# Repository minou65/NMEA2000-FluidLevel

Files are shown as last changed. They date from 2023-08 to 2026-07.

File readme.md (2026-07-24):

# NMEA 2000 Fluidmonitor

<table>
  <tr>
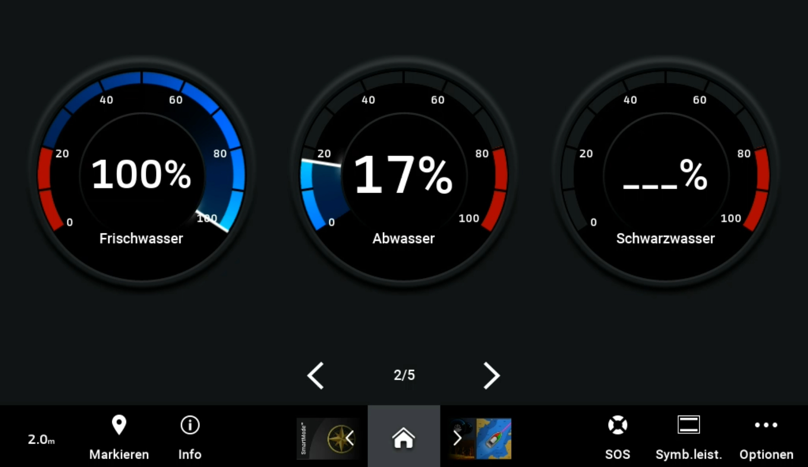
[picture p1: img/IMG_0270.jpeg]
NMEA 2000 Fluidmonitor
    <td></td>
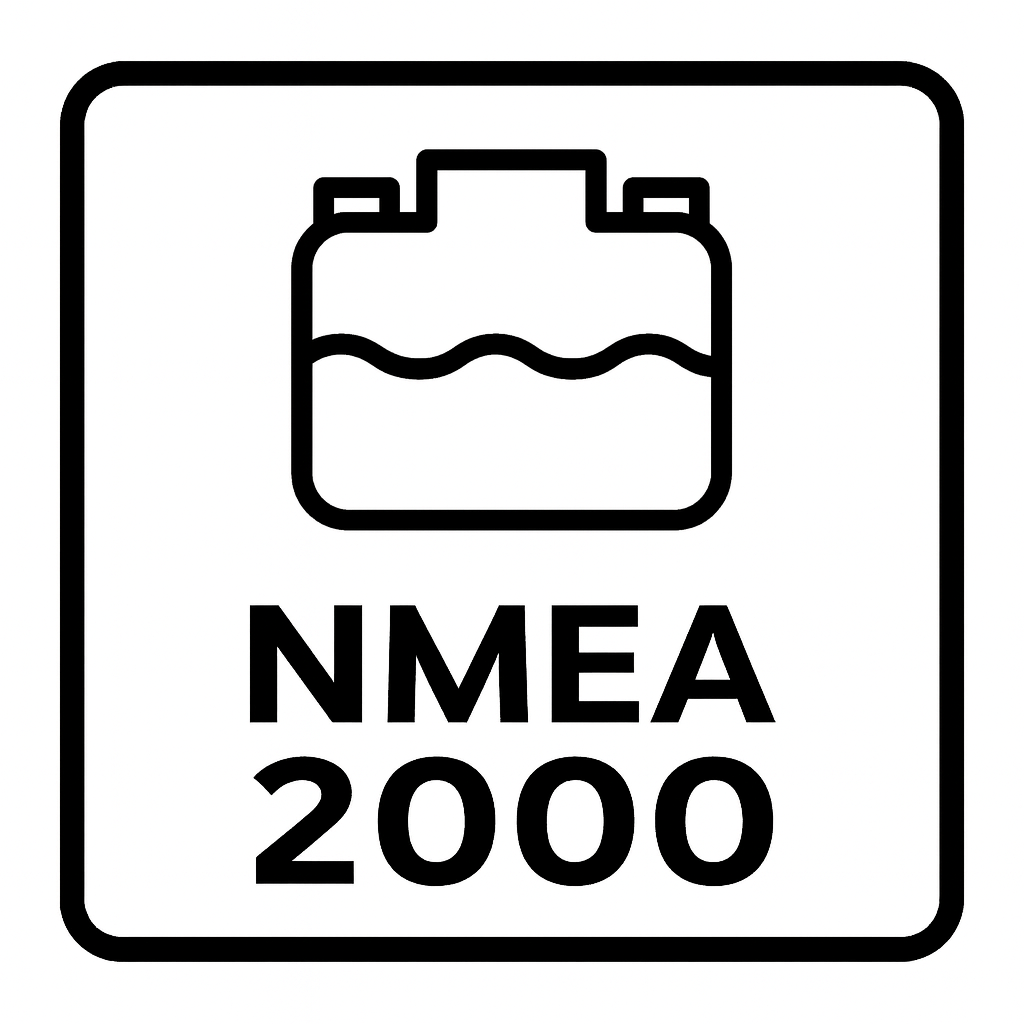
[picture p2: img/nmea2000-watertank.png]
NMEA 2000 Fluidmonitor icon
    <td align="right" valign="top" style="padding-left: 200px;"></td>
  </tr>
</table>

## Table of contents
- [NMEA 2000 Fluidmonitor](#nmea-2000-fluidmonitor)
  - [Table of contents](#table-of-contents)
  - [Important Hint](#important-hint)
  - [Description](#description)
  - [Related Projects](#related-projects)
  - [Hardware](#hardware)
  - [NMEA 2000](#nmea-2000)
  - [Libraries](#libraries)
  - [Configuration](#configuration)
    - [System Configuration](#system-configuration)
    - [NMEA 2000 Settings](#nmea-2000-settings)
    - [Tank](#tank)
    - [Sensor Calibration](#sensor-calibration)
  - [First Start](#first-start)
    - [Default IP address](#default-ip-address)
  - [Operation](#operation)
    - [Web UI (Home/Monitoring page)](#web-ui-homemonitoring-page)
      - [Sensor damping behavior](#sensor-damping-behavior)
    - [Firmware Update](#firmware-update)
    - [Blinking codes](#blinking-codes)
    - [Reset](#reset)

## Important Hint
Although the term NMEA2000 is used here, the software and device are **not certified NMEA2000 products** and have not passed any official approval process. There is a possibility that the software or hardware does not fully comply with the NMEA2000 specification in all details. If you connect this device to your NMEA2000 network, you do so at your own risk.

## Description

Note: This project also provides one branch each for the VL53L1X sensor variant and the VL53L0X sensor variant.

A resistive sensor-based system to determine the fill level in a tank. This device uses a 240-33 Ohm resistive level sensor where:
- **33 Ohm** = Tank FULL (100%)
- **240 Ohm** = Tank EMPTY (0%)
- **Open circuit** (no connection) = Detected as EMPTY
- **Short circuit** (0 Ohm) = Detected as EMPTY

A measurement is taken every second, and the average value is determined from 60 measurements. The system automatically detects fault conditions (open lines and short circuits).

The system communicates via the NMEA 2000 protocol, sending fluid level values as NMEA 2000 messages over an NMEA bus. Configuration is done through a web interface, and real-time values can be viewed on a website. Additionally, there's a link on the configuration page for convenient firmware updates.

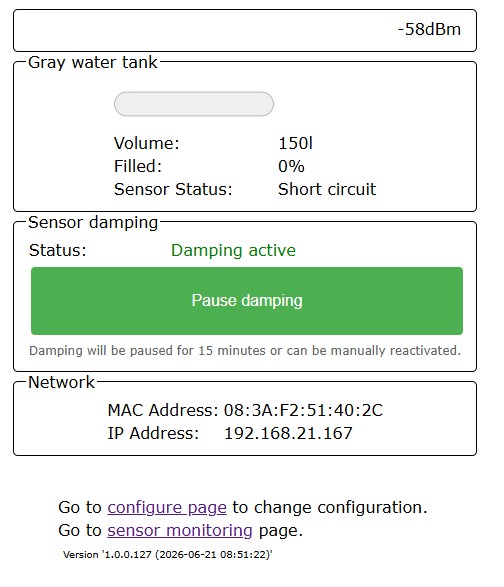
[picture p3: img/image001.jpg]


## Related Projects

| Project | Description |
| --- | --- |
| [NMEA2000-DS1820](https://github.com/minou65/NMEA2000-DS1820) | Temperature monitor for up to 4 DS1820 sensors (-50 C to +125 C) with configurable alerts |
| [NMEA2000-FluidLevel](https://github.com/minou65/NMEA2000-FluidLevel) | Tank fill-level monitor using a VL53L0X time-of-flight sensor |
| [NMEA2000-BME280](https://github.com/minou65/NMEA2000-BME280) | Environmental sensor for temperature, humidity and air pressure |
| [NMEA2000-BatteryMonitor](https://github.com/minou65/NMEA2000-BatteryMonitor) | Battery monitor using an INA226 (voltage, current, SoC, time-to-go) |
| [NMEA2000-SensorBoard](https://github.com/minou65/NMEA2000-SensorBoard/tree/main) | Base hardware platform with schematic, PCB, and printable enclosure |

## Hardware

The hardware of the fluid level is based on the NMEA SensorBoard:

- [minou65/NMEA2000-SensorBoard](https://github.com/minou65/NMEA2000-SensorBoard)

A printable enclosure is also available in the SensorBoard project.

Populate the following components:

| Part | Value | Device | Package |
| --- | --- | --- | --- |
| C1 | 47u/25V | CPOL-EUE5-8.5 | E5-8,5 |
| C2 | 100n | C-EU050-024X044 | C050-024X044 |
| D1 | 1N4001 | 1N4148 | SOD80 |
| IC1 | R-78E05-1.0 | R-78E-XX1.0 | R-78E-XX1.0 |
| IC2 | ESP32_D1_MINI | ESP32_D1_MINI | ESP32_D1_MINI |
| IC3 | MCP2562 | MCP2562SMD | SO-8 |
| R1 | 270R | R-EU_R0805 | R0805 |
| X1 |  | AK500/3 | AK500/3 |
| X2 |  | AK500/2 | AK500/2 |
| X3 | Sender 220-33 Ohm | 22-23-2031 | 22-23-2031 |

Remark: The sender (220-33 Ohm) must be connected to pins X3-2 and X3-3.

Sensor photos:

| Open housing with wiring | Assembled sender |
| --- | --- |
| Open housing with wiring | Assembled sender |

## NMEA 2000

The following PGN is sent by this sensor:

- 127505 (Fluid Level)

## Libraries
- [NMEA2000](https://github.com/ttlappalainen/NMEA2000)
- [NMEA2000_esp32](https://github.com/ttlappalainen/NMEA2000_esp32)
- [AsyncTCP (3.2.6) __"__](https://github.com/mathieucarbou/AsyncTCP)
- [ESPAsyncWebServer (3.3.12) __*__](https://github.com/mathieucarbou/ESPAsyncWebServer)
- [WebSerial (2.0.7) __*__](https://github.com/ayushsharma82/WebSerial)
- [IotWebConf](https://github.com/minou65/IotWebConf)
- [IotWebConfAsync (1.0.2) __*__](https://github.com/minou65/IotWebConfAsync)
- [IotWebRoot](https://github.com/minou65/IotWebRoot)

__*__ new version and/or new repo  
__"__ AsyncTCP fork with additional features

## Configuration
After first boot, open `/config` and set the required values.

Fields marked with __*__ are required for first commissioning.

### System Configuration

| Parameter | Description | Range / Default | Required |
| --- | --- | --- | --- |
| Thing name | Device name. Use letters and `_` (for example `fresh_water`). Avoid spaces and dots. | - | __*__ |
| AP password | Password for later access to the device AP/web UI. | 8..32 chars (recommended: >=12 with mixed classes) | __*__ |
| WiFi SSID | Name of the WiFi network to connect to. | - | __*__ |
| WiFi password | Password of the WiFi network (open networks are not supported). | - | __*__ |
| Startup delay (seconds) | Delay before normal operation starts (IotWebConf AP timeout behavior). | default: **30 s** | optional |
| AP offline mode after (minutes) | Time after startup until AP is disabled. Set `0` to keep WiFi always enabled. | `0..30 min` | optional |

### NMEA 2000 Settings

| Parameter | Description | Range / Default | Required |
| --- | --- | --- | --- |
| Instance | Device instance for PGN 127505. Should be unique for devices sending this PGN. | `1..254` | __*__ |
| SID | Sequence identifier used to correlate PGNs sampled at the same time. | `1..255`, default: **255** | optional |

### Tank

| Parameter | Description | Range / Default | Required |
| --- | --- | --- | --- |
| Fluid type | Select one: Fuel, Water, Gray water, Live well, Oil, Black water, Gasoline fuel. | predefined list | optional |
| Capacity | Tank volume in liters. | `1..1000 l`, default: **150 l** | __*__ |

### Sensor Calibration

This section calibrates the resistive sender used for level calculation.

Calibration options:
1. Removed sender: measure resistance at FULL and EMPTY positions, then enter both values.
2. Installed sender: use `/webserial` to observe the values for FULL and EMPTY, then enter both values.

| Parameter | Description | Range / Default |
| --- | --- | --- |
| Resistance Full (Ohm) | Sender resistance at full tank level. | `1..500 Ohm`, default: **33.0 Ohm** |
| Resistance Empty (Ohm) | Sender resistance at empty tank level. | `1..500 Ohm`, default: **240.0 Ohm** |

## First Start

On first startup, if no WiFi is configured, the device enters AP mode.

- Default AP password: `123456789`

### Default IP address
When running in AP mode, open the web interface at `http://192.168.4.1`.

## Operation

### Web UI (Home/Monitoring page)
The root page (`/`) provides a live monitoring overview:

| Area | Content |
| --- | --- |
| RSSI | Signal strength in dBm |
| Tank | Tank type, fill bar (%), volume (l), fill value (%), sensor status (`OK`, `Open circuit`, `Short circuit`) |
| Sensor damping | Current damping state and control button |
| Network | MAC address and current IP address |
| Links | `/config` (configuration), `/webserial` (sensor monitoring) |

#### Sensor damping behavior

| State / Action | Behavior |
| --- | --- |
| Default | **Damping active** |
| Press **Pause damping** | Damping is disabled for 15 minutes |
| While paused | Button shows **Enable damping (mm:ss)**, status is **Damping paused**, output uses current reading (not averaged) |
| End of pause | Damping is re-enabled automatically after 15 minutes, or immediately via **Enable damping** |

### Firmware Update
1. Open `/config`.
2. Select the **Firmware Update** link.
3. Follow the on-screen update instructions.

### Blinking codes
The LED blink pattern indicates the current operating mode:

| Blinking Pattern | Meaning |
| --- | --- |
| Rapid blinking <br>(mostly on, interrupted by short off periods) | Access Point mode is active. The device creates its own WiFi network for setup. |
| Alternating on/off blinking | Trying to connect to the configured WiFi network. |
| Mostly off with occasional short flash | The device is online. |
| Mostly off with occasional long flash | The device is in offline mode. |

### Reset
To recover access (for example after losing credentials), pull `CONFIG_PIN` to GND during startup.
The device then starts AP mode using the initial password.

Reset pin: `GPIO 13`

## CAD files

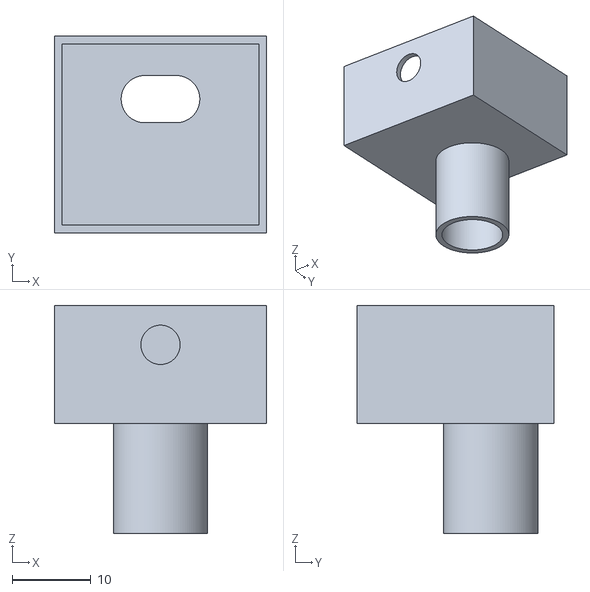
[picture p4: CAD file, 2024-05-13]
stl/NEMA Lasersensor-v2.stl
27.0 x 25.0 x 29.0

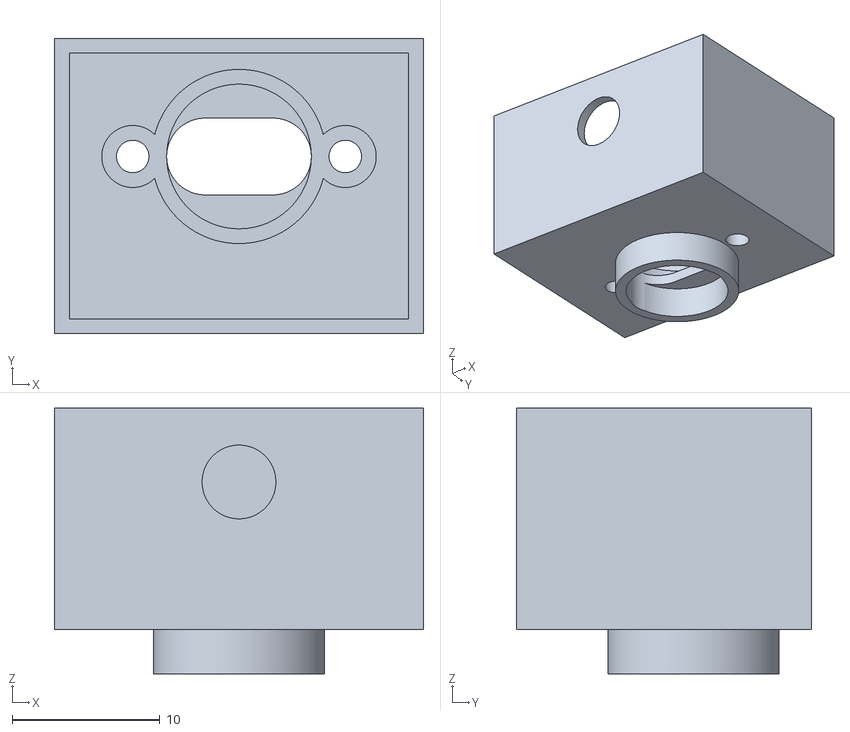
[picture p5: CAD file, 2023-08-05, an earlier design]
stl/NEMA Lasersensor.stl
25.0 x 20.0 x 18.0

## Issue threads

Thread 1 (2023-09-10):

Calibration factor

minou65, 2023-09-10:
Der calibration factor funktioniert falsch herum

minou65, 2024-07-03:
fixed with Version 1.1.0

Closed 2024-07-03.

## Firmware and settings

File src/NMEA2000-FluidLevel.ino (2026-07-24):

// ============================================================================
// NMEA2000 Fluid Level Sensor - Resistive Sensor (240-33 Ohm)
// ============================================================================
// Sensor: 240-33 Ohm resistive level sensor
// - 33 Ohm  = Tank FULL (100%)
// - 240 Ohm = Tank EMPTY (0%)
// - Open circuit (infinite resistance) = Tank EMPTY
// - Short circuit (0 Ohm) = Tank EMPTY
// ============================================================================;

// ============================================================================
// BOARD CONFIGURATION
// ============================================================================
// Select your target board by uncommenting ONE of the following definitions:
// - Uncomment the board you are using
// - Leave all others commented out
// ============================================================================

#define BOARD_WEMOS_D1_MINI_ESP32       // Wemos D1 Mini ESP32
// #define BOARD_NODE32S                // NodeMCU-32S
// #define BOARD_ESP32_DEVKIT           // ESP32 DevKit V1
// #define BOARD_CUSTOM                 // Custom board (define pins below)


#if defined(BOARD_WEMOS_D1_MINI_ESP32)
    // ----------------------------------------------------
    // Wemos D1 Mini ESP32 Pin Configuration
    // ----------------------------------------------------
#define ESP32_CAN_TX_PIN GPIO_NUM_5     // CAN Bus TX Pin
#define ESP32_CAN_RX_PIN GPIO_NUM_4     // CAN Bus RX Pin
#define SENSOR_PIN       GPIO_NUM_36    // ADC pin for resistive sensor (VP, ADC1_CH0)

#define BOARD_NAME "Wemos D1 Mini ESP32"
#define BOARD_INFO "Standard Wemos D1 Mini ESP32 configuration"

#define DISABLE_BROWNOUT_DETECTOR

#elif defined(BOARD_NODE32S)
    // ----------------------------------------------------
    // NodeMCU-32S Pin Configuration
    // ----------------------------------------------------
#define ESP32_CAN_TX_PIN GPIO_NUM_5     // CAN Bus TX Pin
#define ESP32_CAN_RX_PIN GPIO_NUM_4     // CAN Bus RX Pin
#define SENSOR_PIN       GPIO_NUM_22    // ADC pin for resistive sensor (VP, ADC1_CH0)

#define BOARD_NAME "NodeMCU-32S"
#define BOARD_INFO "NodeMCU-32S standard configuration"
#elif defined(BOARD_CUSTOM)
    // ----------------------------------------------------
    // Custom Board Pin Configuration
    // ----------------------------------------------------
    // Define your custom pin assignments here
#define ESP32_CAN_TX_PIN GPIO_NUM_17    // CAN Bus TX Pin (customize)
#define ESP32_CAN_RX_PIN GPIO_NUM_16    // CAN Bus RX Pin (customize)
#define ONE_WIRE_BUS     GPIO_NUM_25    // DS18B20 OneWire Data Pin (customize)

#define BOARD_NAME "Custom ESP32 Board"
#define BOARD_INFO "User-defined custom pin configuration"

#else
    // ----------------------------------------------------
    // No Board Selected - Compilation Error
    // ----------------------------------------------------
#error "ERROR: No valid board configuration selected! Please uncomment ONE board definition at the top of this file."
#error "Available options: BOARD_WEMOS_D1_MINI_ESP32, BOARD_NODE32S, BOARD_ESP32_DEVKIT, BOARD_CUSTOM"

#endif

// #define DEBUG_NMEA_MSG_ASCII // If you want to use simple ascii monitor like Arduino Serial Monitor, uncomment this line
// #define DEBUG_NMEA_Actisense // Uncomment this, so you can test code without CAN bus chips on Arduino Mega
// #define DEBUG_MSG

// ============================================================================
// RESISTIVE SENSOR CONFIGURATION
// ============================================================================

#define REFERENCE_RESISTOR   270.0f   // Reference resistor in voltage divider (Ohm)
#define ADC_VOLTAGE           3.3f    // ADC reference voltage
#define ADC_RESOLUTION       4095.0f  // 12-bit ADC resolution
#define ADC_SAMPLES            10     // Number of ADC samples for averaging

// Resistance thresholds for fault detection
#define RESISTANCE_MIN         10.0f  // Below this = short circuit (fault)
#define RESISTANCE_MAX        500.0f  // Above this = open circuit (fault)

// ============================================================================
// INCLUDES
// ============================================================================
#include <Arduino.h>
#include <esp_mac.h>
#include <N2kMessages.h>
#include <NMEA2000_CAN.h>
#include <Preferences.h>
#include <esp_task_wdt.h>
#include <RebootManager.h>
#include <time.h>
#include <sys/time.h>
#include <driver/twai.h>

#include "common.h"
#include "webhandling.h"
#include "version.h"

// ============================================================================
// GLOBAL VARIABLES
// ============================================================================
bool debugMode = false;
char Version[] = VERSION_STR;
bool ParamsSave = false;

tN2kSyncScheduler FluidLevelScheduler(false, 2500, 500);
tN2kSyncScheduler MeasurementScheduler(true, 1000, 0);

RingBuf<float, TANK_RINGBUF_SIZE> gAverageFillLevel;
String SensorStatus = "";

bool TimeSet = false;
unsigned long LastTimeUpdate = 0;

// ============================================================================
// FUNCTION DECLARATIONS
// ============================================================================
float readResistance();
float calculateFillLevel(float resistance);
float getAverageFillLevel();
void initSensor();
String getCurrentTime();
void handleN2kMessages(const tN2kMsg& N2kMsg);
void ParseN2kSystemTime(const tN2kMsg& N2kMsg);
void ParseN2kGNSS(const tN2kMsg& N2kMsg);

// NMEA2000 message handlers
typedef struct {
    unsigned long PGN;
    void (*Handler)(const tN2kMsg& N2kMsg);
} tNMEA2000Handler;

tNMEA2000Handler NMEA2000Handlers[] = {
    {126992L, ParseN2kSystemTime},  // System Time
    {129029L, ParseN2kGNSS},        // GNSS Position Data
    {0, 0}
};

// List of messages to receive
const unsigned long ReceiveMessages[] PROGMEM = {
    126992L,  // System Time
    129029L,  // GNSS Position Data
    0
};

// List here messages your device will transmit.
const unsigned long TransmitMessages[] PROGMEM = {
    127505L,  // Fluid Level
    0
};

// ============================================================================
// TIME SYNCHRONIZATION FUNCTIONS
// ============================================================================

/**
 * Set ESP32 system time from NMEA2000 time
 */
void SetSystemTime(uint16_t DaysSince1970, double SecondsSinceMidnight) {
    if (DaysSince1970 == 0xFFFF || SecondsSinceMidnight > 86400) {
        return;
    }
    
    // Update only every 10 minutes (except first time)
    if (TimeSet && (millis() - LastTimeUpdate < 600000)) {
        return;
    }
    
    time_t timestamp = (DaysSince1970 * 86400UL) + (time_t)SecondsSinceMidnight;
    
    struct timeval tv;
    tv.tv_sec = timestamp;
    tv.tv_usec = 0;
    settimeofday(&tv, NULL);
    
    TimeSet = true;
    LastTimeUpdate = millis();
    
    char timeStr[64];
    struct tm* timeinfo = localtime(&timestamp);
    strftime(timeStr, sizeof(timeStr), "%Y-%m-%d %H:%M:%S", timeinfo);
    Serial.printf("System time set from NMEA2000: %s UTC\n", timeStr);
}

/**
 * Parse PGN 126992 - System Time
 */
void ParseN2kSystemTime(const tN2kMsg& N2kMsg) {
    unsigned char SID;
    uint16_t SystemDate;
    double SystemTime;
    tN2kTimeSource TimeSource;
    
    if (ParseN2kPGN126992(N2kMsg, SID, SystemDate, SystemTime, TimeSource)) {
        if (TimeSource == N2ktimes_GPS || TimeSource == N2ktimes_GLONASS) {
            SetSystemTime(SystemDate, SystemTime);
            
            if (debugMode) {
                Serial.printf("Received System Time (PGN 126992): Date=%u, Time=%.1fs, Source=%d\n",
                    SystemDate, SystemTime, TimeSource);
            }
        }
    }
}

/**
 * Parse PGN 129029 - GNSS Position Data (contains time)
 */
void ParseN2kGNSS(const tN2kMsg& N2kMsg) {
    unsigned char SID;
    uint16_t DaysSince1970;
    double SecondsSinceMidnight;
    double Latitude;
    double Longitude;
    double Altitude;
    tN2kGNSStype GNSStype;
    tN2kGNSSmethod GNSSmethod;
    unsigned char nSatellites;
    double HDOP;
    double PDOP;
    double GeoidalSeparation;
    unsigned char nReferenceStations;
    tN2kGNSStype ReferenceStationType;
    uint16_t ReferenceSationID;
    double AgeOfCorrection;
    
    if (ParseN2kPGN129029(N2kMsg, SID, DaysSince1970, SecondsSinceMidnight,
                          Latitude, Longitude, Altitude, GNSStype, GNSSmethod,
                          nSatellites, HDOP, PDOP, GeoidalSeparation,
                          nReferenceStations, ReferenceStationType,
                          ReferenceSationID, AgeOfCorrection)) {
        
        SetSystemTime(DaysSince1970, SecondsSinceMidnight);
        
        if (debugMode) {
            Serial.printf("Received GNSS Time (PGN 129029): Date=%u, Time=%.1fs, Sats=%u\n",
                DaysSince1970, SecondsSinceMidnight, nSatellites);
        }
    }
}

/**
 * Handle incoming NMEA2000 messages
 */
void handleN2kMessages(const tN2kMsg& N2kMsg) {
    for (uint8_t i = 0; NMEA2000Handlers[i].PGN != 0; i++) {
        if (N2kMsg.PGN == NMEA2000Handlers[i].PGN) {
            NMEA2000Handlers[i].Handler(N2kMsg);
            break;
        }
    }
}

// ============================================================================
// NMEA2000 CALLBACK
// ============================================================================
void OnN2kOpen() {
    FluidLevelScheduler.UpdateNextTime();
    MeasurementScheduler.UpdateNextTime();
}

void CheckN2kSourceAddressChange() {
    if (!NMEA2000.ReadResetAddressChanged()) {
        return;
    }

	uint8_t newSource = NMEA2000.GetN2kSource();
    Serial.printf("NMEA2000 source address changed to %u\n", newSource);
    Preferences prefs;
    prefs.begin("n2k", false);
    prefs.putUChar("N2KSource", newSource);
	prefs.end();
}

// ============================================================================
// SETUP
// ============================================================================
void setup() {
    uint8_t chipid[6];
    uint32_t id = 0;

    esp_efuse_mac_get_default(chipid);
    for (int i = 0; i < 6; i++) id += (chipid[i] << (7 * i));

    Serial.begin(115200);
    while (!Serial) {
        static unsigned long startWait = millis();
        if (millis() - startWait > 3000) break;
    }

    Serial.println("\n========================================");
    Serial.println("Hardware Configuration Check");
    Serial.println("========================================");
    Serial.printf("Board: %s\n", BOARD_NAME);
    Serial.printf("CAN TX Pin: GPIO%d\n", ESP32_CAN_TX_PIN);
    Serial.printf("CAN RX Pin: GPIO%d\n", ESP32_CAN_RX_PIN);
    Serial.printf("Sensor Pin: GPIO%d\n", SENSOR_PIN);
    Serial.println("CAN Transceiver: MCP2562");
    Serial.println("========================================");

    Serial.println("========================================");
    Serial.println("NMEA2000 Resistive Fluid Level Sensor");
    Serial.println("========================================");
    Serial.printf("Firmware version: %s\n", Version);
    Serial.println("Sensor type: Resistive (240-33 Ohm)");
    Serial.printf("Sensor pin: GPIO_%d\n", SENSOR_PIN);
    Serial.println("========================================\n");

    RebootManager::begin();
    Serial.printf("Reboot count: %d\n", RebootManager::getRebootCount());
    Serial.printf("Last reboot reason: %s\n", RebootManager::getLastRebootReasonText().c_str());

    Serial.println("\nInitializing sensor...");
    initSensor();

    Serial.println("\nInitializing WiFi...");
    wifiInit();

    Serial.println("\n========================================");
    Serial.println("Setting up NMEA2000...");
    Serial.println("========================================");

    // load N2K source address from Preferences if available
    Preferences prefs_;
    prefs_.begin("n2k", true); // read-only
    uint8_t source_ = prefs_.getUChar("N2KSource", 22); // fallback: default 22
    prefs_.end();

    Serial.printf("Requested N2K Source Address: %u\n", source_);

    NMEA2000.SetN2kCANMsgBufSize(8);
    NMEA2000.SetN2kCANReceiveFrameBufSize(150);
    NMEA2000.SetN2kCANSendFrameBufSize(150);
    Serial.println("Buffer sizes configured");

    NMEA2000.SetProductInformation(
        "1",
        100,
        "Resistive Level Sensor 240-33",
        Version,
        Version,
        1,
        0xffff,
        0xff
    );
    Serial.println("Product information set");

    NMEA2000.SetDeviceInformation(
        id,
        150,
        75,
        2040
    );
    Serial.println("Device information set");

    NMEA2000.SetConfigurationInformation(
        String(id).c_str(),
        iotWebConf.getThingName(),
        ""
    );
    Serial.println("Configuration information set");

    NMEA2000.EnableForward(false);
    NMEA2000.SetMode(tNMEA2000::N2km_NodeOnly);
    NMEA2000.SetN2kSource(source_);

    NMEA2000.ExtendTransmitMessages(TransmitMessages);
//    NMEA2000.ExtendReceiveMessages(ReceiveMessages);

//    NMEA2000.SetMsgHandler(handleN2kMessages);
    NMEA2000.SetOnOpen(OnN2kOpen);
    
    NMEA2000.Open();

    esp_task_wdt_add(NULL);
}

// ============================================================================
// SENSOR FUNCTIONS
// ============================================================================

/**
 * Initialize ADC for resistive sensor
 */
void initSensor() {
    Serial.println("  Configuring ADC...");
    pinMode(SENSOR_PIN, INPUT);
    analogSetAttenuation(ADC_11db);
    analogReadResolution(12);

    Serial.println("  Taking test reading...");
    float testResistance_ = readResistance();

    Serial.printf("  Test resistance: %.1f Ohm\n", testResistance_);

    if (testResistance_ >= RESISTANCE_MIN && testResistance_ <= RESISTANCE_MAX) {
        SensorStatus = "Ok";
        Serial.printf("  Sensor OK: %.1f Ohm\n", testResistance_);
        Serial.printf("  Fill level: %.1f%%\n", calculateFillLevel(testResistance_));
    }
    else if (testResistance_ < RESISTANCE_MIN) {
        SensorStatus = "Short circuit";
        Serial.println("  WARNING: Short circuit detected!");
    }
    else {
        SensorStatus = "Open circuit";
        Serial.println("  WARNING: Open circuit detected!");
    }

    Serial.println("Sensor initialization complete");
}

/**
 * Read resistance from sensor using voltage divider
 * Circuit: 3.3V --- R_ref --- ADC_PIN --- R_sensor --- GND
 */
float readResistance() {
    uint32_t adcSum_ = 0;

    for (int i_ = 0; i_ < ADC_SAMPLES; i_++) {
        adcSum_ += analogRead(SENSOR_PIN);
        delayMicroseconds(1000);
    }

    float adcAverage_ = (float)adcSum_ / ADC_SAMPLES;
    float voltage_ = (adcAverage_ / ADC_RESOLUTION) * ADC_VOLTAGE;

    if (voltage_ <= 0.01f) {
        return 0.0f;
    }
    if (voltage_ >= (ADC_VOLTAGE - 0.01f)) {
        return 999.0f;
    }

    float resistance_ = REFERENCE_RESISTOR * voltage_ / (ADC_VOLTAGE - voltage_);

    return resistance_;
}
/**
 * Convert resistance to fill level percentage
 * Automatically handles both orientations:
 * - FULL < EMPTY (e.g., 33? -> 205?)
 * - FULL > EMPTY (e.g., 240? -> 33?)
 */
float calculateFillLevel(float resistance) {
    float resistanceFull_ = sensorConfig.getResistanceFull();
    float resistanceEmpty_ = sensorConfig.getResistanceEmpty();

    // Auto-detect if values are inverted
    if (resistanceFull_ > resistanceEmpty_) {
        // Swap values: User configured it backwards
        float temp_ = resistanceFull_;
        resistanceFull_ = resistanceEmpty_;
        resistanceEmpty_ = temp_;
    }

    // Handle faults
    if (resistance < RESISTANCE_MIN || resistance > RESISTANCE_MAX) {
        return 0.0f;  // Report empty on fault
    }

    // Clamp resistance to valid range
    if (resistance < resistanceFull_) resistance = resistanceFull_;
    if (resistance > resistanceEmpty_) resistance = resistanceEmpty_;

    // Linear interpolation
    // resistanceFull_ -> 100%, resistanceEmpty_ -> 0%
    float fillLevel_ = 100.0f - ((resistance - resistanceFull_) /
        (resistanceEmpty_ - resistanceFull_) * 100.0f);

    // Clamp to 0-100%
    if (fillLevel_ < 0.0f) fillLevel_ = 0.0f;
    if (fillLevel_ > 100.0f) fillLevel_ = 100.0f;

    // Round to 1 decimal place
    fillLevel_ = round(fillLevel_ * 10.0f) / 10.0f;

    return fillLevel_;
}

/**
 * Get averaged fill level from ring buffer
 */
float getAverageFillLevel() {
    if (gAverageFillLevel.size() == 0) {
        return 0.0f;
    }

    float sum_ = 0.0f;
    for (uint8_t i = 0; i < gAverageFillLevel.size(); i++) {
        sum_ += gAverageFillLevel[i];
    }

    return sum_ / gAverageFillLevel.size();
}

/**
 * Get current fill level (most recent reading)
 */
float getCurrentFillLevel() {
    // Returns the last added value from the ring buffer without averaging
    // This is the most recent sensor reading
    if (gAverageFillLevel.size() > 0) {
        return gAverageFillLevel[gAverageFillLevel.size() - 1];
    }
    return 0.0f;
}

/**
 * Get current time as string
 */
String getCurrentTime() {
    time_t now_ = time(nullptr);
    struct tm* timeInfo_ = localtime(&now_);

    char buffer_[9];
    strftime(buffer_, sizeof(buffer_), "%H:%M:%S", timeInfo_);

    return String(buffer_);
}

/**
 * Read sensor and update fill level
 */
void MeasureFillLevel() {
    if (SensorStatus != "Ok") {
        if (debugMode) {
            WebSerial.printf("%s : Sensor fault: %s\n", getCurrentTime().c_str(), SensorStatus.c_str());
        }
        return;
    }

    // Read resistance
    float resistance_ = readResistance();

    // Check for faults
    if (resistance_ < RESISTANCE_MIN) {
        SensorStatus = "Short circuit";
        if (debugMode) {
            Serial.printf("%s : Short circuit detected (%.1f Ohm)\n", getCurrentTime().c_str(), resistance_);
        }
        gAverageFillLevel.pushOverwrite(0.0f);
        return;
    }

    if (resistance_ > RESISTANCE_MAX) {
        SensorStatus = "Open circuit";
        if (debugMode) {
            Serial.printf("%s : Open circuit detected (%.1f Ohm)\n", getCurrentTime().c_str(), resistance_);
        }
        gAverageFillLevel.pushOverwrite(0.0f);
        return;
    }

    // Reset status if it was faulty before
    if (SensorStatus != "Ok") {
        SensorStatus = "Ok";
        if (debugMode) {
            Serial.println("Sensor recovered");
        }
    }

    // Calculate fill level
    float fillLevel_ = calculateFillLevel(resistance_);

    // Add to ring buffer
    gAverageFillLevel.pushOverwrite(fillLevel_);

    // Get average
    float avgFillLevel_ = getAverageFillLevel();

    // Debug output (only if debugMode is enabled)
    if (debugMode) {
        Serial.printf("%s : Resistance: %.1f Ohm | Fill: %.1f%% | Avg: %.1f%%\n",
            getCurrentTime().c_str(), resistance_, fillLevel_, avgFillLevel_);
    }

    WebSerial.printf("%s : Resistance: %.1f Ohm | Fill: %.1f%% | Avg: %.1f%%\n",
        getCurrentTime().c_str(), resistance_, fillLevel_, avgFillLevel_);

    // Detect fast changes (>10% threshold)
    float threshold_ = 10.0f;
    if (abs(fillLevel_ - avgFillLevel_) > threshold_) {
        if (debugMode) {
            Serial.printf("Fast change detected: %.1f%% -> %.1f%%\n", avgFillLevel_, fillLevel_);
        }
        // Reset buffer with new value
        for (int i_ = 0; i_ < TANK_RINGBUF_SIZE; i_++) {
            gAverageFillLevel.pushOverwrite(fillLevel_);
        }
    }
}
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
void loop() {
    SendN2kFluidLevel();
    NMEA2000.ParseMessages();
    wifiLoop();

    CheckN2kSourceAddressChange();

    if (MeasurementScheduler.IsTime()) {
        MeasurementScheduler.UpdateNextTime();
        MeasureFillLevel();
    }

    if (NMEA2000.GetN2kSource() != Config.Source()) {
        Config.SetSource(NMEA2000.GetN2kSource());
        ParamsSave = true;
    }

    if (ParamsChanged) {
        ParamsChanged = false;
        NMEA2000.SetInstallationDescription1(iotWebConf.getThingName());
    }
    
    if (TimeSet && (millis() - LastTimeUpdate > 3600000)) {
        Serial.println("Warning: No time update received for 1 hour");
        TimeSet = false;
    }

    if (Serial.available()) {
        Serial.read();
    }

    esp_task_wdt_reset();
}

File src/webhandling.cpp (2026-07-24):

#include <Arduino.h>
#include <ArduinoOTA.h>
#include <WiFi.h>

#include "common.h"
#include "webhandling.h"
#include "favicon.h"
#include "neotimer.h"

#include <DNSServer.h>
#include <IotWebConfAsyncUpdateServer.h>
#include <IotWebRoot.h>
#include <Preferences.h>

// -- Configuration specific key. The value should be modified if config structure was changed.
#define CONFIG_VERSION "A7"

// -- When CONFIG_PIN is pulled to ground on startup, the Thing will use the initial
//      password to buld an AP. (E.g. in case of lost password)
#define CONFIG_PIN  GPIO_NUM_13

// -- Status indicator pin.
//      First it will light up (kept LOW), on Wifi connection it will blink,
//      when connected to the Wifi it will turn off (kept HIGH).
#define STATUS_PIN LED_BUILTIN
#define ON_LEVEL HIGH

// -- Initial name of the Thing. Used e.g. as SSID of the own Access Point.
const char thingName[] = "NMEA2000-FluidLevel";

uint8_t APModeOfflineTime = 0;
Neotimer APModeTimer = Neotimer();

// Damping pause functionality
bool DampingPaused = false;
Neotimer DampingPauseTimer = Neotimer(15 * 60 * 1000); // 15 Minuten

// -- Method declarations.
void onWebSerialMessage(uint8_t* data, size_t len);
void handleData(AsyncWebServerRequest* request);
void handleRoot(AsyncWebServerRequest* request);
void handleToggleDamping(AsyncWebServerRequest* request);
void convertParams();

// -- Callback methods.
void configSaved();
void wifiConnected();

bool ParamsChanged = true;

DNSServer dnsServer;
AsyncWebServer server(80);
AsyncWebServerWrapper asyncWebServerWrapper(&server);
AsyncUpdateServer AsyncUpdater;

AsyncIotWebConf iotWebConf(thingName, &dnsServer, &asyncWebServerWrapper, wifiInitialApPassword, CONFIG_VERSION);

char APModeOfflineValue[STRING_LEN];
iotwebconf::NumberParameter APModeOfflineParam = iotwebconf::NumberParameter("AP offline mode after (minutes)", "APModeOffline", APModeOfflineValue, NUMBER_LEN, "0", "0..30", "min='0' max='30', step='1'");

NMEAConfig Config = NMEAConfig();
Tank tank = Tank("tank", "Tank configuration");
SensorConfig sensorConfig;

class CustomHtmlFormatProvider : public iotwebconf::HtmlFormatProvider {
protected:
    virtual String getFormEnd() {
        String s_ = HtmlFormatProvider::getFormEnd();
        s_ += F("</br>Return to <a href='/'>home page</a>.");
        return s_;
    }
};
CustomHtmlFormatProvider customHtmlFormatProvider;

class MyHtmlRootFormatProvider : public HtmlRootFormatProvider {
public:
    virtual String getScriptInner() {
        String s_ = HtmlRootFormatProvider::getScriptInner();
        s_.replace("{millisecond}", "1000");
        s_ += F("function updateData(jsonData) {\n");
        s_ += F("   document.getElementById('RSSIValue').innerHTML = jsonData.rssi + \"dBm\" \n");

        s_ += F("   const tankelement = document.getElementById('tankValue'); \n");
        s_ += F("   tankelement.value = jsonData.filledpercent; \n");
        s_ += F("   tankelement.innerHTML = jsonData.filledpercent; \n");
        s_ += F("   document.getElementById('capacityValue').innerHTML = jsonData.capacity; \n");
        s_ += F("   document.getElementById('filledpercentValue').innerHTML = jsonData.filledpercent; \n");
        s_ += F("   document.getElementById('statusValue').innerHTML = jsonData.status; \n");
        
        // Damping status update
        s_ += F("   const dampingBtn = document.getElementById('dampingBtn'); \n");
        s_ += F("   if (jsonData.dampingPaused) { \n");
        s_ += F("       dampingBtn.innerHTML = 'Enable damping (' + jsonData.dampingRemaining + ')'; \n");
        s_ += F("       dampingBtn.className = 'button button-on'; \n");
        s_ += F("       document.getElementById('dampingStatus').innerHTML = 'Damping paused'; \n");
        s_ += F("       document.getElementById('dampingStatus').style.color = 'orange'; \n");
        s_ += F("   } else { \n");
        s_ += F("       dampingBtn.innerHTML = 'Pause damping'; \n");
        s_ += F("       dampingBtn.className = 'button'; \n");
        s_ += F("       document.getElementById('dampingStatus').innerHTML = 'Damping active'; \n");
        s_ += F("       document.getElementById('dampingStatus').style.color = 'green'; \n");
        s_ += F("   } \n");
        s_ += F("}\n");
        
        // Toggle damping function
        s_ += F("function toggleDamping() {\n");
        s_ += F("   fetch('/toggledamping').then(() => getData());\n");
        s_ += F("}\n");

        return s_;
    }
    
    virtual String getStyleInner() {
        String s_ = HtmlRootFormatProvider::getStyleInner();
        s_ += F(".button { \n");
        s_ += F("   background-color: #4CAF50; \n");
        s_ += F("   border: none; \n");
        s_ += F("   color: white; \n");
        s_ += F("   padding: 15px 32px; \n");
        s_ += F("   text-align: center; \n");
        s_ += F("   text-decoration: none; \n");
        s_ += F("   display: inline-block; \n");
        s_ += F("   font-size: 16px; \n");
        s_ += F("   margin: 4px 2px; \n");
        s_ += F("   cursor: pointer; \n");
        s_ += F("   border-radius: 4px; \n");
        s_ += F("} \n");
        s_ += F(".button-on { \n");
        s_ += F("   background-color: #ff9800; \n");
        s_ += F("} \n");
        return s_;
    }
};
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

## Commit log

2023-09-06 use VL53L0X as sensor
2023-10-11 initial version
    [NMEA2000-FluidLevel.sch]
2024-01-02 timers changed
2024-03-22 fixed panic when sensor is not connected
    [NMEA2000-FluidLevel.ino]
2024-05-13 use arduinojson for generating json
2024-05-13 fix reading I2C bus when sensor is not connected
    [NMEA2000-FluidLevel.ino]
2024-05-17 use printf instead of buffer
2024-05-18 ERROR: Too many messages queued
    [NMEA2000-FluidLevel.ino]
2024-05-18 fix a buffer overflow
    [NMEA2000-FluidLevel.ino, webhandling.cpp]
2024-05-25 Write calibration factor to webserial
2024-07-03 added some missing values
    [NMEA2000-FluidLevel.sch]
2024-07-09 schema updated
    [NMEA2000-FluidLevel.sch]
2024-07-26 task watchdog timer added
2024-10-08 Updated to ESPAsyncWebServer version 3.3.12 and removed dependency on ArduinoJson
2025-04-14 Refactor Watchdog Timer configuration and initialization in NMEA2000-FluidLevel.ino
2025-05-30 Set ArduinoOTA hostname to the Thing's name in convertParams function
2025-09-13 Refactor sensor handling and configuration in NMEA2000-FluidLevel.ino
2025-09-13 Update NMEA2000 setup to include detailed sensor information and configuration
2026-07-04 feat: add resistive sensor support
    [NMEA2000-FluidLevel.sch]
2026-07-24 fix: improve favicon handling with cache control and ETag headers
    [webhandling.cpp]
2026-07-24 fix: correct CAN pin assignments and enhance setup logging for NMEA2000
    [NMEA2000-FluidLevel.ino]
2026-07-31 feat: implement tabbed interface for tank, sensor, and system information in web handling
2026-08-10 feat: add board configuration handling to Config.h and refactor main file to include it - v1.0.3.213
2026-08-10 feat: update board configuration for NMEA Sensor Board
2026-08-10 fix: update sender resistance value in documentation from 220-33 Ohm to 240-33 Ohm
2026-08-22 Add EventLogger and WebSerial integration to FluidLevel
    - Replace Serial.print* with eventLogger.log/logf for centralized logging
    - Integrate WebSerial with live event streaming and command handling
    - Add connection tracking to auto-send event history to new clients
    - Update reference resistor to 330Ω and improve sensor calibration
